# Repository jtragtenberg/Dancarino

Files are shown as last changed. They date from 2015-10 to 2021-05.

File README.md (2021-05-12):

# Jerimum
open source IMU

23/10/2015
Fala Rodrigo, novas instruções para o commit "adicionei arquivos de arduino e processing do Motioner para ler RAW e…":

Pelo código estar uma gambiarra só, primeiro estude os quaternions e só depois mande esse código novo pro arduino pra ver os dados RAW... 
e pra te ajudar no descoberta de como os quaternions funcionam:
q = <qw,qx,qy,qz> = <cos(teta/2) , x*sen(teta/2) , y*sen(teta/2) , z*sen(teta/2)>
onde x,y,z é o eixo para onde aponta o vetor que representa o quaternion e teta é o angulo de rotação em torno desse eixo.
tenta descobrir como retornar a partir do quaternion os valores de x,y,z e teta limpos...
Ah! descobri!
olha esse site aqui: http://www.euclideanspace.com/maths/geometry/rotations/conversions/quaternionToAngle/
brincando com uma identidade trigonométrica básia se descobre que:
teta = 2 * acos(qw)
x = qx / sqrt(1-qw*qw)
y = qy / sqrt(1-qw*qw)
z = qz / sqrt(1-qw*qw)

de mão bejada pra tu! (assim fica fácil...)

Depois de ter dominado os quaternions, pra testar o lance com os valores RAW dos sensores, tu faz o seguinte: Pega na pasta /Arduino a pasta IMUDebug. Ali tem o firmware pra mandar os dados calibrados dos sensores e na pasta libraries tem as bibliotecas que ele depende. Tu deve colocar todas as bibliotecas da pasta libraries na pasta do teu computador (X:\My Documents\Arduino\libraries\). Aí tu abre com a ide do arduino o IMUDebug.ino e upa ele pro arduino naquele esquema que eu te falei (escolhe a placa Arduino UNO em Tools>Boards e a porta serial que ele tá em Tools>Serial Port. Aí dá o Run e é só alegria (finger-crossed)
Daí em diante o arduino vai estar com esse firmware e só vai dar pra rodar os novos programas de processing que eu coloquei na pasta /Processing.
São os programas (todos eles levam em conta o magnetometros e as calibrações que já estão na memória EEPROM do arduino): 
IMUVisualization //gera uma visualização a partir dos dados de Yaw Pitch e Roll do sensor e retorna todos os valores de YPR
razorReadYPR //lê direto os valores Yaw Pitch e Roll do sensor
razorReadRaw //lê os valores brutos dos sensores
razorReadGyro //lê só os valores do giroscópio (n tenho certeza se esse funciona)

beleza?

qq coisa a gente se fala

abração.

Oi Rodrigo
O arduino que fiz pra vcs com o MPU6050 e o HMC5883L já está com o código MPU6050_DMP6.
Para fazer o IMU rodar agora, precisa 
- instalar o processing 2;
- clonar esse repositório
- instalar as bibliotecas que estão aqui no git na pasta /Processing/Libraries (pra fazer isso copia as duas pastas pra pasta /Processing/libraries;
- dar três pulinhos
- abrir o código Teapot que ta na pasta Processing
- conectar o arduino no usb
- executar o código do processing
- se aparecer alguma mensagem de erro, da uma olhada no numero das portas seriais e muda a variavel PORT_NUMBER para o numero da porta em que está conectado o arduino. (Se não sabe qual eh a porta tira e ve qual da lista sumiu...). Elas estão expostas na ordem 0, 1, 2,... Vai ser alguma COM# no windows...
- veja o aviãzinho girar com os quaternions...
- descubra agora no código como ele faz isso e se estiver muito pilhado tenta implementar o mesmo código no OpenFrameWorks

abração!

ps. as vezes da um mal contato com o USB e precisa tirar da usb, colocar denovo e reiniciar o código do processing

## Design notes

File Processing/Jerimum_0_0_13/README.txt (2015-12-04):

alou! lembrando que tenq substituir o RazorIMU.cpp da pasta de libraries do arduino pelo que esta neste diretorio.

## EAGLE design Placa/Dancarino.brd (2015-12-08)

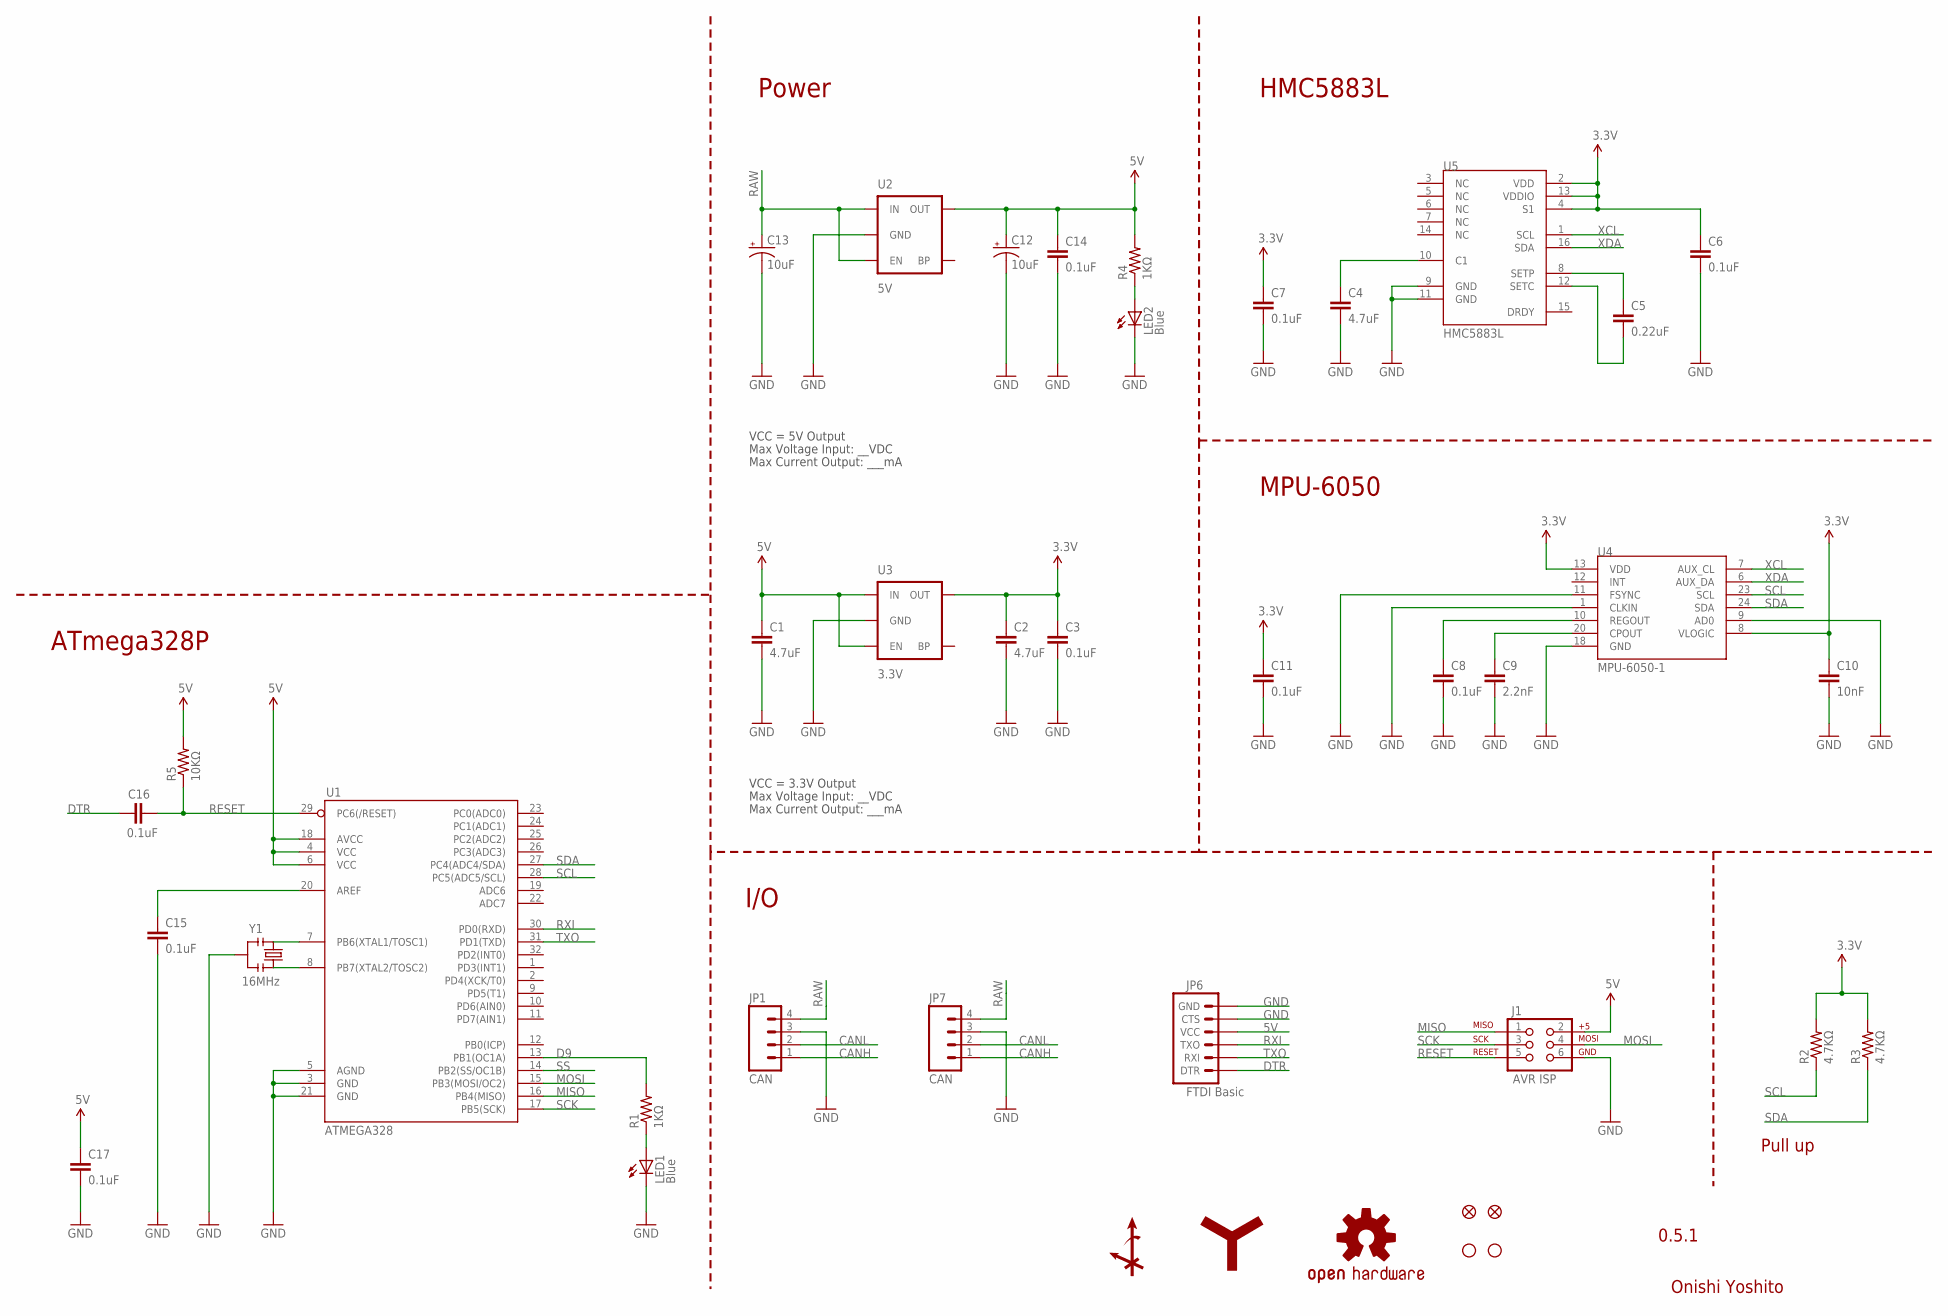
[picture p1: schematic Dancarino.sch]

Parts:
C1, C2, C4: 4.7uF; 0402-CAP
C3, C6, C7, C8, C11, C14, C15, C16, C17: 0.1uF; 0402-CAP
C5: 0.22uF; 0402-CAP
C9: 2.2nF; 0402-CAP
C10: 10nF; 0402-CAP
C12, C13: 10uF; EIA3216
J1: AVR ISP; 2X3-NS
JP1, JP7: CAN; JST-4-PTH
JP2, JP5: FIDUCIALUFIDUCIAL; MICRO-FIDUCIAL
JP3, JP4: STAND-OFFTIGHT; STAND-OFF-TIGHT
JP6: FTDI Basic; 1X06
LED1, LED2: Blue; LED-0603
R1, R4: 1KΩ; 0402-RES
R2, R3: 4.7KΩ; 0402-RES
R5: 10KΩ; 0402-RES
U1: ATMEGA328; TQFP32-08
U2: 5V; SOT23-5
U3: 3.3V; SOT23-5
U4: MPU-6050-1; QFN-24-4MM2
U5: HMC5883L; 16LPCC
U$2: OSHW-LOGOS; OSHW-LOGO-S
U$11: AXIS-ANGLE_S
U$13: YCAM_LOGO_L
Y1: 16MHz; RESONATOR-SMD

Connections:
3.3V: C2.1, C3.1, C6.1, C7.1, C10.1, C11.1, R2.2, R3.2, U3.5 (OUT), U4.8 (VLOGIC), U4.13 (VDD), U5.2 (VDD), U5.4 (S1), U5.13 (VDDIO)
5V: C1.1, C12.A (+), C14.1, C17.1, J1.2, JP6.4 (VCC), R4.2, R5.2, U1.4 (VCC), U1.6 (VCC), U1.18 (AVCC), U2.5 (OUT), U3.1 (IN), U3.3 (EN)
CANH: JP1.1, JP7.1
CANL: JP1.2, JP7.2
D9: R1.2, U1.13 (PB1(OC1A))
DTR: C16.1, JP6.1 (DTR)
GND: C1.2, C2.2, C3.2, C4.2, C6.2, C7.2, C8.2, C9.2, C10.2, C11.2, C12.C (-), C13.C (-), C14.2, C15.2, C17.2, J1.6, JP1.3, JP6.5 (CTS), JP6.6 (GND), JP7.3, LED1.C, LED2.C, U1.3 (GND), U1.5 (AGND), U1.21 (GND), U2.2 (GND), U3.2 (GND), U4.1 (CLKIN), U4.9 (AD0), U4.11 (FSYNC), U4.18 (GND), U5.9 (GND), U5.11 (GND), Y1.2
MISO: J1.1, U1.16 (PB4(MISO))
MOSI: J1.4, U1.15 (PB3(MOSI/OC2))
unnamed: LED1.A, R1.1
unnamed: LED2.A, R4.1
unnamed: C4.1, U5.10 (C1)
unnamed: C5.1, U5.8 (SETP)
unnamed: C5.2, U5.12 (SETC)
unnamed: C9.1, U4.20 (CPOUT)
unnamed: C8.1, U4.10 (REGOUT)
unnamed: U1.7 (PB6(XTAL1/TOSC1)), Y1.1
unnamed: U1.8 (PB7(XTAL2/TOSC2)), Y1.3
unnamed: C15.1, U1.20 (AREF)
RAW: C13.A (+), JP1.4, JP7.4, U2.1 (IN), U2.3 (EN)
RESET: C16.2, J1.5, R5.1, U1.29 (PC6(/RESET))
RXI: JP6.3 (TXO), U1.30 (PD0(RXD))
SCK: J1.3, U1.17 (PB5(SCK))
SCL: R2.1, U1.28 (PC5(ADC5/SCL)), U4.23 (SCL)
SDA: R3.1, U1.27 (PC4(ADC4/SDA)), U4.24 (SDA)
SS: U1.14 (PB2(SS/OC1B))
TXO: JP6.2 (RXI), U1.31 (PD1(TXD))
XCL: U4.7 (AUX_CL), U5.1 (SCL)
XDA: U4.6 (AUX_DA), U5.16 (SDA)

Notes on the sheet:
Onishi Yoshito
0.5.1
HMC5883L
MPU-6050
Pull up
Max Voltage Input: __VDC
Max Current Output: ___mA
VCC = 3.3V Output
VCC = 5V Output
ATmega328P
Power
I/O

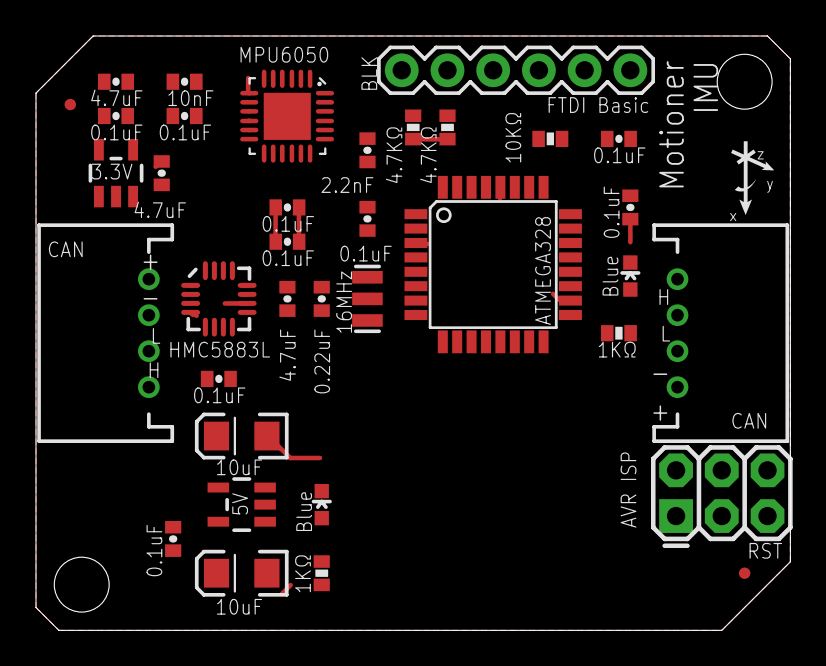
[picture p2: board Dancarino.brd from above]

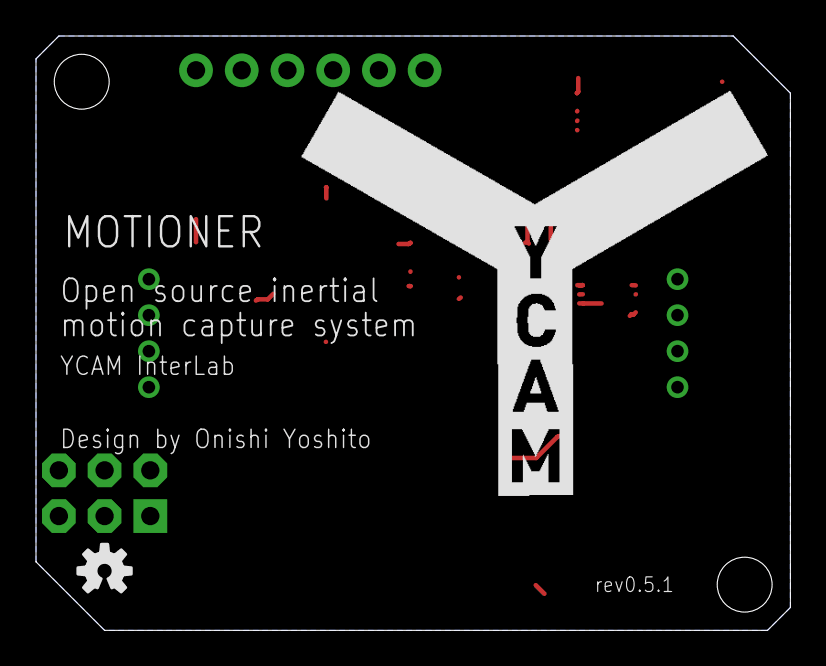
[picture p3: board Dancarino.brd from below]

Board: 2 copper layers, 41.9 x 33.0 mm, 41 parts (2 on the bottom side), 28 nets.

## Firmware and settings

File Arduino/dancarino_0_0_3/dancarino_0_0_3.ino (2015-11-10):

/// MotionerIMU using the follwing libraries
#include "CAN.h"
#include "vec3.h"
#include "EEPROM.h"
#include "Wire.h"
#include "SPI.h"
#include "I2Cdev.h"
#include "MPU60X0.h"
#include "RazorIMU.h"
#include "MotionerIMU.h"


/// Our serial baudrate
static const long BAUDRATE = 57600;

/// MotionerIMU object
MotionerIMU motioner;


/// setup
void setup()
{
  /// Use serial for get some information from MotionerIMU
  Serial.begin(BAUDRATE);

  Serial.println("[Motioner IMU]");

  /// Use I2C
  Wire.begin();

  /// Setup MotionerIMU
  motioner.setup();
}


/// main loop
void loop()
{
  /// Update MotionerIMU
  motioner.update();
  uint8_t dancarinoPacket[12] = { 
    '$', 0x02, 0,0 ,0,0, 0,0, 0,0, '\r', '\n'       };
  int w = int((motioner.mRazorIMU.quat.w + 1)*100);
  int x = int((motioner.mRazorIMU.quat.x + 1)*100);
  int y = int((motioner.mRazorIMU.quat.y + 1)*100);
  int z = int((motioner.mRazorIMU.quat.z + 1)*100);

  float qx = motioner.mRazorIMU.getQuatX();
  float qy = motioner.mRazorIMU.getQuatY();
  float qz = motioner.mRazorIMU.getQuatZ();
  float qw = motioner.mRazorIMU.getQuatW();  
  
  
  Serial.print(qw);
  Serial.print('|');
  Serial.print(qx);
  Serial.print('|');
  Serial.print(qy);
  Serial.print('|');  
  Serial.println(qz);

 /*
   Serial.print(motioner.mRazorIMU.quat.w);
  Serial.print('|');
  Serial.print(motioner.mRazorIMU.quat.x);
  Serial.print('|');
  Serial.print(motioner.mRazorIMU.quat.y);
  Serial.print('|');  
  Serial.println(motioner.mRazorIMU.quat.z);
*/
/*
  Serial.print(motioner.mRazorIMU.yaw);
  Serial.print('|');
  Serial.print(motioner.mRazorIMU.pitch);
  Serial.print('|');
  Serial.println(motioner.mRazorIMU.roll);
*

  dancarinoPacket[2] = x >> 8 & B11111111;
  dancarinoPacket[3] = x & B11111111;
  dancarinoPacket[4] = y >> 8 & B11111111;
  dancarinoPacket[5] = y & B11111111;
  dancarinoPacket[6] = z >> 8 & B11111111;
  dancarinoPacket[7] = z & B11111111;
  dancarinoPacket[8] = w >> 8 & B11111111;
  dancarinoPacket[9] = w & B11111111;

/*
  int teste = 21759;
  uint8_t testePacket[2] = {
    0,0  };
  testePacket[0] = teste >> 8;
  testePacket[1] = teste & B11111111;

  Serial.print(testePacket[0]);
  Serial.print('|');
  Serial.println(testePacket[1]);
*/

   // Serial.write(dancarinoPacket, sizeof(dancarinoPacket));

    delay(10);
}

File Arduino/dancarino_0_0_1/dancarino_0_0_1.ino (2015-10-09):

///
/// MotionerIMU firmware
///
/// Developed by Onishi Yoshito
///
/// IMU node firmware for MOTIONER which is an opensource inertial motion capture system
/// https://github.com/YCAMInterlab/MOTIONER
/// Using a part of FreeIMU hardware, canduino library, Razor AHRS Firmware v1.4.1 and I2Cdevlib
/// See also the follwing sites
/// http://www.varesano.net/topic/freeimu
/// http://code.google.com/p/canduino/
/// https://dev.qu.tu-berlin.de/projects/sf-razor-9dof-ahrs
/// http://www.i2cdevlib.com/
///
/// Copyright Onishi Yoshito and YCAM InterLab all rights reserved
/// This Arduino sketch is published under the GNU GENERAL PUBLIC LICENSE Version 3
/// 
/// version: 0.2.2
///
/// -- MotionerIMU serial command --
/// "@q" - output current quaternion
/// "@n" - change mode to writting joint id to Arduino EEPROM
/// joint id are from 0 to 18
/// and a command for set joint id is to type single character after typed @n from 'a' to 'r'
/// 'a' mean 0, 'b' mean 1, 'c' mean 2 ...... 'r' mean 17
/// so we need to type like @na (set joint id to JOINT_HIPS)
/// 
/// MOTIONER joint id and commands
///
/// - joint name -        - index -  - command -
/// JOINT_HIPS              = 0,       @na
/// JOINT_ABDOMEN           = 1,       @nb
/// JOINT_CHEST             = 2,       @nc
/// JOINT_NECK              = 3,       @nd
///   
/// JOINT_LEFT_HIP          = 4,       @ne
/// JOINT_LEFT_KNEE         = 5,       @nf
/// JOINT_LEFT_ANKLE        = 6,       @ng
///   
/// JOINT_RIGHT_HIP         = 7,       @nh
/// JOINT_RIGHT_KNEE        = 8,       @ni
/// JOINT_RIGHT_ANKLE       = 9,       @nj
///   
/// JOINT_LEFT_COLLAR       = 10,      @nk
/// JOINT_LEFT_SHOULDER     = 11,      @nl
/// JOINT_LEFT_ELBOW        = 12,      @nm
/// JOINT_LEFT_WRIST        = 13,      @nn
///   
/// JOINT_RIGHT_COLLAR      = 14,      @no
/// JOINT_RIGHT_SHOULDER    = 15,      @np
/// JOINT_RIGHT_ELBOW       = 16,      @nq
/// JOINT_RIGHT_WRIST       = 17,      @nr
///   
/// NUM_JOINTS              = 18,
///
/// -- Extended RazorAHRS serial command --
/// "#co" - output calibration data on Arduino EEPROM
///
///


/// MotionerIMU using the follwing libraries
#include "CAN.h"
#include "vec3.h"
#include "EEPROM.h"
#include "Wire.h"
#include "SPI.h"
#include "I2Cdev.h"
#include "MPU60X0.h"
#include "RazorIMU.h"
#include "MotionerIMU.h"


/// Our serial baudrate
static const long BAUDRATE = 57600;

/// MotionerIMU object
MotionerIMU motioner;


/// setup
void setup()
{
  /// Use serial for get some information from MotionerIMU
  Serial.begin(BAUDRATE);

  Serial.println("[Motioner IMU]");

  /// Use I2C
  Wire.begin();

  /// Setup MotionerIMU
  motioner.setup();
}


/// main loop
void loop()
{
  /// Update MotionerIMU
  motioner.update();
  uint8_t dancarinoPacket[12] = { 
    '$', 0x02, 0,0 ,0,0, 0,0, 0,0, '\r', '\n'     };
  int w = (motioner.mRazorIMU.quat.w + 1)*16384;
  int x = (motioner.mRazorIMU.quat.x + 1)*16384;
  int y = (motioner.mRazorIMU.quat.y + 1)*16384;
  int z = (motioner.mRazorIMU.quat.z + 1)*16384;
  
  dancarinoPacket[2] = w >> 8 & B11111111;
  dancarinoPacket[3] = w & B11111111;
  dancarinoPacket[4] = x >> 8 & B11111111;
  dancarinoPacket[5] = x & B11111111;
  dancarinoPacket[6] = y >> 8 & B11111111;
  dancarinoPacket[7] = y & B11111111;
  dancarinoPacket[8] = z >> 8 & B11111111;
  dancarinoPacket[9] = z & B11111111;

  Serial.write(dancarinoPacket, sizeof(dancarinoPacket));

//  delay(3);
}

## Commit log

2015-10-09 deixei a porta serial mais facil de mudar no teapot
2015-10-23 adicionei arquivos de arduino e processing do Motioner para ler RAW e YPR values
2015-12-04 A volta de Franklin
    [Project8_1.cfg]
2015-12-08 GUI Melhorada
    [Dancarino.brd, Dancarino.sch]
2015-12-08 posição inicial do getSeed, Seeds com MIDI_Channel e coloquei classe de EffectsPadXY
2015-12-09 Botoes na interface, nome de arquivos de config e atalhos atualizados
2015-12-10 voltou a funcionar!

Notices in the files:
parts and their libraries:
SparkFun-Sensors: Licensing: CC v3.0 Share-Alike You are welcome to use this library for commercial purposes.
